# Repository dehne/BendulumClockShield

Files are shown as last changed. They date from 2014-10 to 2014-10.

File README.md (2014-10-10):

# Bendulum Clock Shield

Bendulum Clock Shield Copyright 2014 by D. L. Ehnebuske  
License terms: [Creative Commons Attribution-ShareAlike 3.0 United States (CC BY-SA 3.0 US)]
(http://creativecommons.org/licenses/by-sa/3.0/us/ "CC BY-SA 3.0 US")

This is the more complex of two Arduino shields that implement the hardware interface between an 
Arduino Uno that drives a bendulum clock and the rest of the bendulum clock. The other is the 
EscapementShield. This one is more complex in that it implements a battery backup. If the power 
fails, the clock keeps going!

The Rev H version adds a header for the Sparkfun TMP-102 temperature sensor (for temperature 
compensated operation) and removes the potentiometers for the clock and coil as experiments 
have shown it is possible to get the needed control in software.

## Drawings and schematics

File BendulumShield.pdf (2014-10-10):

# Bendulum Clock Shield

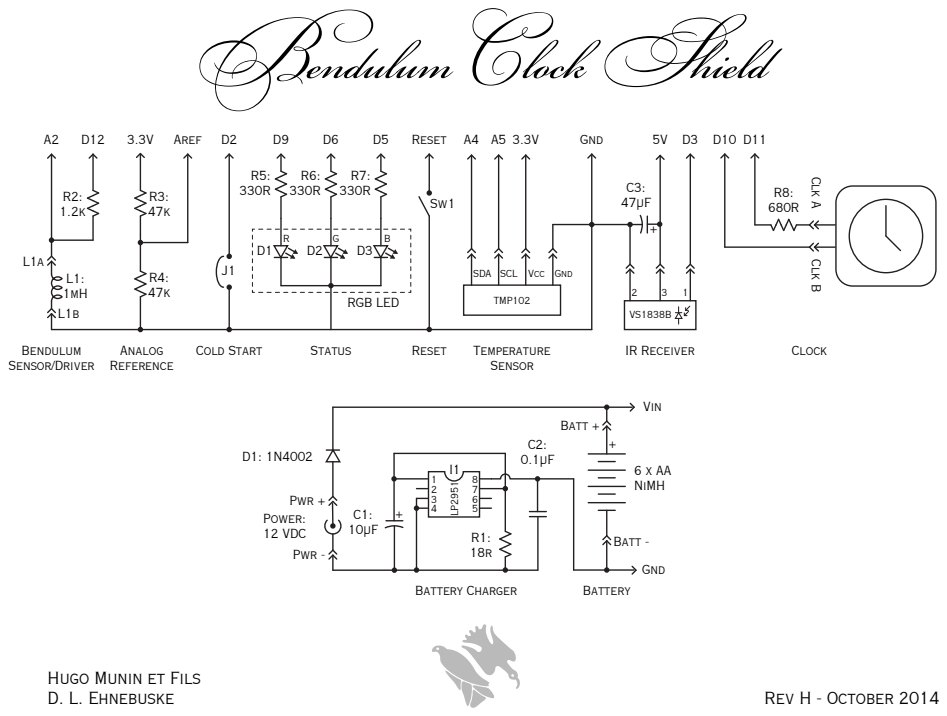
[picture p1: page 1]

Hugo Munin et Fils
D. L. Ehnebuske

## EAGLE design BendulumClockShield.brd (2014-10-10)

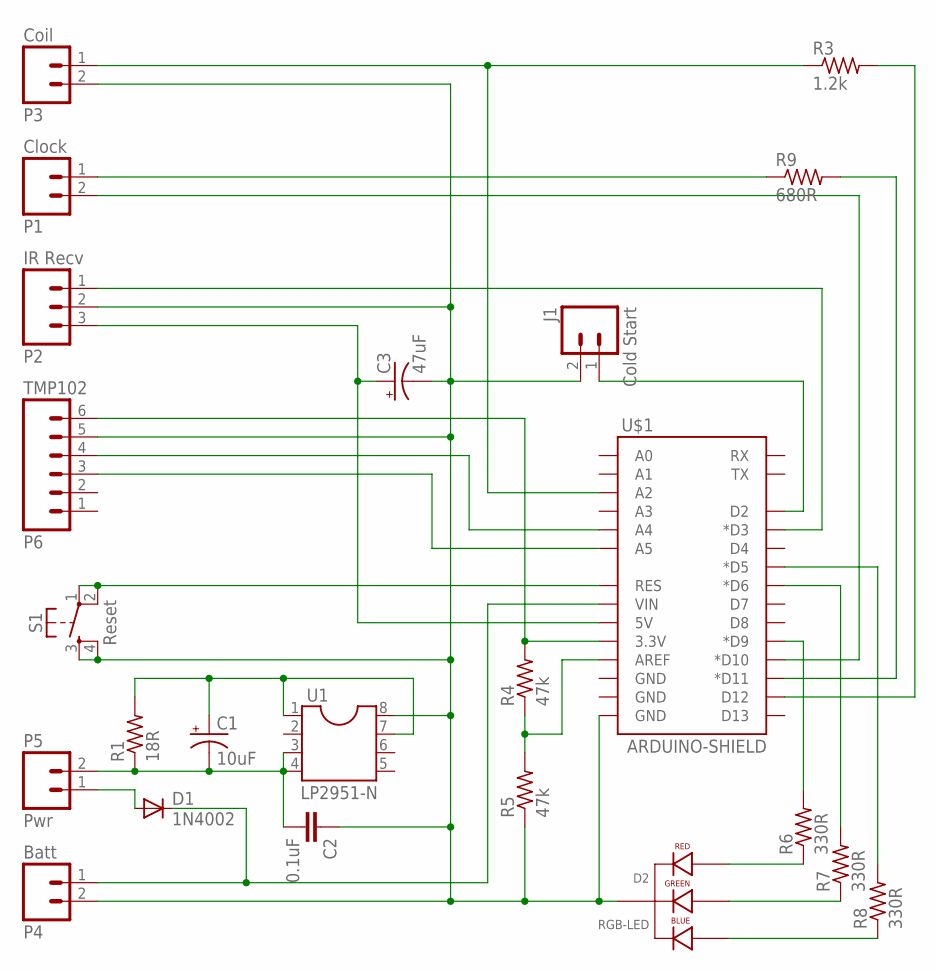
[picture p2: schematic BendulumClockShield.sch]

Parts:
C1: 10uF; CPOL-RADIAL-10UF-25V
C2: 0.1uF; CAP-PTH-5MM
C3: 47uF; CPOL-RADIAL-10UF-25V
D1: 1N4002; DIODE-1N4001-KIT
D2: RGB-LED; LED-RGB-THRU
J1: Cold Start; 1X02
P1: Clock; 1X02
P2: IR Recv; 1X03
P3: Coil; 1X02
P4: Batt; 1X02
P5: Pwr; 1X02
R1: 18R; AXIAL-0.4
R3: 1.2k; AXIAL-0.4
R4, R5: 47k; AXIAL-0.4
R6, R7, R8: 330R; AXIAL-0.4
R9: 680R; AXIAL-0.4
S1: Reset; TACTILE-PTH
TMP102: P6; 1X06
U1: LP2951-N; SOCKET-08
U$1: ARDUINO-SHIELD; DUEMILANOVE_SHIELD

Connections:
GND: C2.1, C3.2 (-), D2.2 (CATHODE), J1.2, P2.2, P3.2, P4.2, R5.P$1 (1), S1.3, S1.4, TMP102.5, U1.8 (INPUT), U$1.GND@0 (GND)
unnamed: D1.A, P5.1
unnamed: D1.C, P4.1, U$1.VIN
unnamed: C1.2 (-), C2.2, P5.2, R1.P$1 (1), U1.3 (SHUTDOWN), U1.4 (GND)
unnamed: S1.1, S1.2, U$1.RES
unnamed: R6.P$2 (2), U$1.D9 (*D9)
unnamed: P3.1, R3.P$1 (1), U$1.A2
unnamed: R4.P$2 (2), TMP102.6, U$1.3.3V
unnamed: R3.P$2 (2), U$1.D12
unnamed: TMP102.4, U$1.A4
unnamed: J1.1, U$1.D2
unnamed: R4.P$1 (1), R5.P$2 (2), U$1.AREF
unnamed: R7.P$2 (2), U$1.D6 (*D6)
unnamed: R8.P$2 (2), U$1.D5 (*D5)
unnamed: P2.1, U$1.D3 (*D3)
unnamed: C3.1 (+), P2.3, U$1.5V
unnamed: TMP102.3, U$1.A5
unnamed: D2.1 (RED_ANODE), R6.P$1 (1)
unnamed: D2.3 (GREEN_ANODE), R7.P$1 (1)
unnamed: D2.4 (BLUE_ANODE), R8.P$1 (1)
unnamed: P1.2, U$1.D10 (*D10)
unnamed: P1.1, R9.P$1 (1)
unnamed: R9.P$2 (2), U$1.D11 (*D11)
U1: C1.1 (+), R1.P$2 (2), U1.1 (OUTPUT), U1.7 (FEEDBACK)

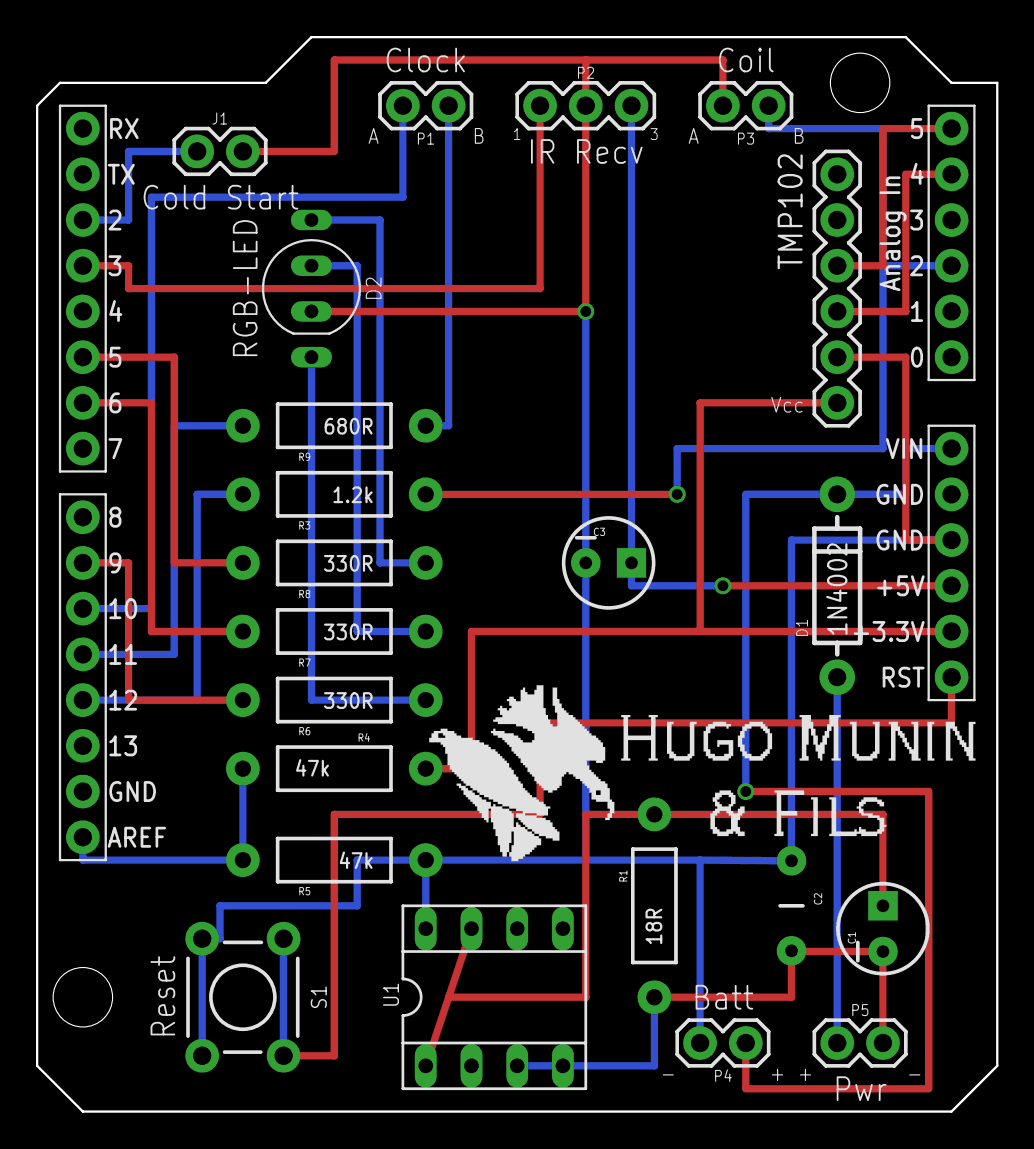
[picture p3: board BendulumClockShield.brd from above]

Board: 2 copper layers, 53.3 x 59.7 mm, 24 parts (0 on the bottom side), 24 nets.

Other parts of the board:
U$2: HMF-LOGO

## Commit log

2014-04-25 origin
    Initial commit
    [BendulumClockShield.brd, BendulumClockShield.sch]
2014-04-26 Add schematic
    Add the conventional schematic for the clock shield
2014-04-30 Update to Rev G
    Increase current drive to 68mA; 42mA for the Arduino and 26mA to keep
    the the battery pack fully charged. (26mA is 0.01C for 2500mAh
    batteries.)
    [BendulumClockShield.brd, BendulumClockShield.sch]
2014-10-10 Update to Rev H
    Add header for TMP-102 temperature sensor
    [BendulumClockShield.brd, BendulumClockShield.sch]
2014-10-10 Add Rev H schematic
    Add schematic as a pdf

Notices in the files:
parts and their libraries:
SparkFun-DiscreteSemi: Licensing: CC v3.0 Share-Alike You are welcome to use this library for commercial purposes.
